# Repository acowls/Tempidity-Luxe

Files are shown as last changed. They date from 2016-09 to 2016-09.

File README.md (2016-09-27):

# Tempidity-Luxe
A sensor board for TI OPT3001 Ambient Light Sensor and the TI HDC1080 Low Power, High Accuracy Digital Humidity Sensor with Temperature Sensor.

This board samples the following:
* Light (lux)
* Relative Humidity (%)
* Temperature (degrees celcius)

While this board is protyping friendly (aka bread-board) it is intdened that it be conected to a hosting board for production use. 
For accurtate readings the sensors require no objects to be near them that could reflect or generate heat. 
Having these sensors isolated on this “daughter" board provides flexibile deployment options. 
To order one go to my profile on OSH Park: [https://oshpark.com/profiles/SeaOwl]

If you are looking for libraries to use this with an Arduino then take a look here:
* https://github.com/closedcube/ClosedCube_HDC1080_Arduino
and
* https://github.com/closedcube/ClosedCube_OPT3001_Arduino
for examples.

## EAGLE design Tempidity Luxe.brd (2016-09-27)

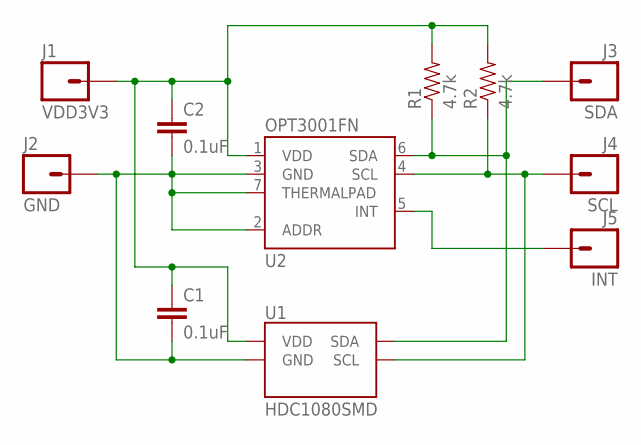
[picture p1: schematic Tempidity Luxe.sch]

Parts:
C1, C2: 0.1uF; 0805
J1: VDD3V3; 1X01_NO_SILK
J2: GND; 1X01_NO_SILK
J3: SDA; 1X01_NO_SILK
J4: SCL; 1X01_NO_SILK
J5: INT; 1X01_NO_SILK
R1, R2: 4.7k; 0805
U1: HDC1080SMD; TI-PWSON6-DMB
U2: OPT3001FN; TI-USON6-GND-PAD

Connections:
GND: C1.2, C2.2, J2.1, U1.GND, U2.2 (ADDR), U2.3 (GND), U2.7 (THERMALPAD)
N$INT: J5.1, U2.5 (INT)
SCL: J4.1, R2.1, U1.SCL, U2.4 (SCL)
SDA: J3.1, R1.1, U1.SDA, U2.6 (SDA)
VDD: C1.1, C2.1, J1.1, R1.2, R2.2, U1.VDD, U2.1 (VDD)

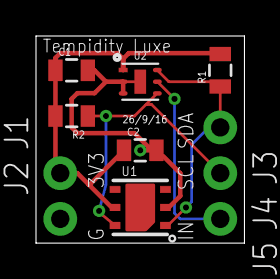
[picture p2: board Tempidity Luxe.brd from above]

Board: 2 copper layers, 11.6 x 11.5 mm, 11 parts (0 on the bottom side), 5 nets.

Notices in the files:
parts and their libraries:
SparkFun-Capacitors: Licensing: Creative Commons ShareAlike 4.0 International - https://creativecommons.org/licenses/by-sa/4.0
